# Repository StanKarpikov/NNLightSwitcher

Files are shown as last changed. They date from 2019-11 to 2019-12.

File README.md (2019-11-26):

### NNLightSwitcher - Xilinx Zynq board

The project serves educational purposes, therefore, the maximum number of modules that fit on a small board was used.

Main components on the board:
- Main processing unit: Zynq-7000 SoC (Z-7010) in CLG225 package (FPGA and two ARM Cortex-A9 cores running at 666 MHz)
- Memory: DDR3L 1066 MHz 512 Mb (IS43TR16256AL-125KBL)
- eMMC 8 Gb (MTFC8GAKAJCN-1M WT)
- QSPI Configuration memory (W25Q32JVZPIQ)
- Qi, WPC 1.1 wireless charger 5W (BQ51013BRHLT)
- Battery powering and charging unit (LTC4155EUFD)
- WiFi WLAN(11a/b/g/n/ac) dual band 2.4/5Ghz +BT/BLE(BT5.0) combo SIP module Murata Type1MW with Cypress CYW43455 with chip antenna
- Connectors: USB Type-C (UART), HDMI
- Two MEMS microphones (ICS-40300)

**Hardware** folder includes Altium Designer project for the PCB and schematic.
- Board dimensions: 68 x 42 mm
- Board layers: 6
- Minimum hole: 0.2 mm
- Minimum trace width/gap: 0.1/0.1 mm
- Immersion gold plating (ENIG) is used to ensure surface quality for the BGA chips.

**Enclosure** folder includes STL models for the 3D printed enclosure (made in Blender).

**Software** is in progress. 

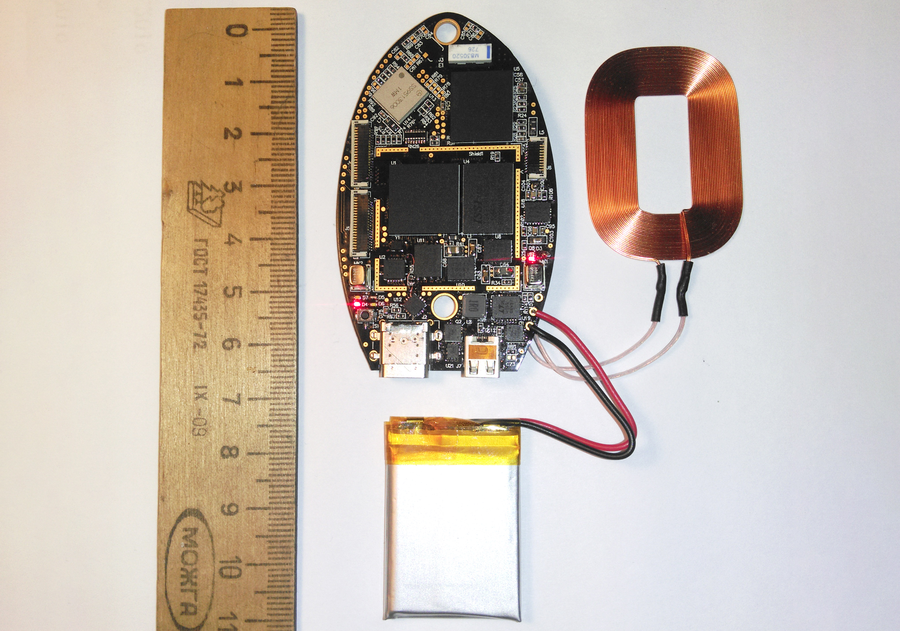
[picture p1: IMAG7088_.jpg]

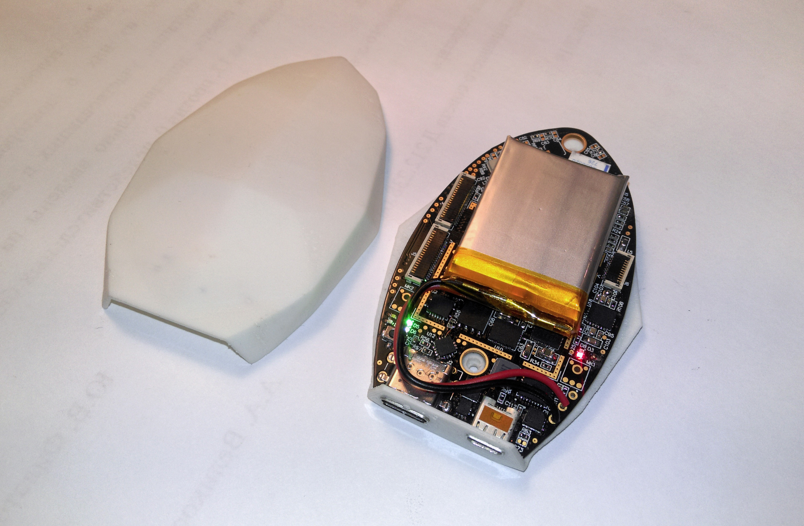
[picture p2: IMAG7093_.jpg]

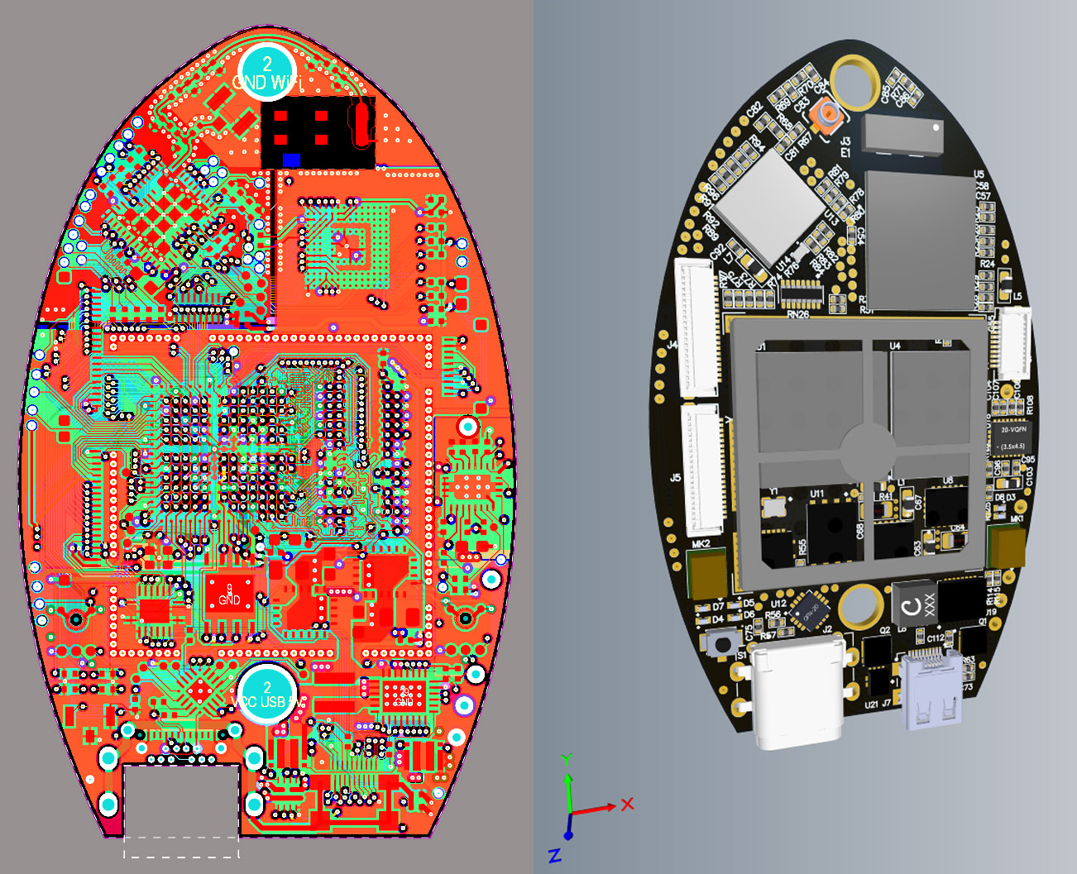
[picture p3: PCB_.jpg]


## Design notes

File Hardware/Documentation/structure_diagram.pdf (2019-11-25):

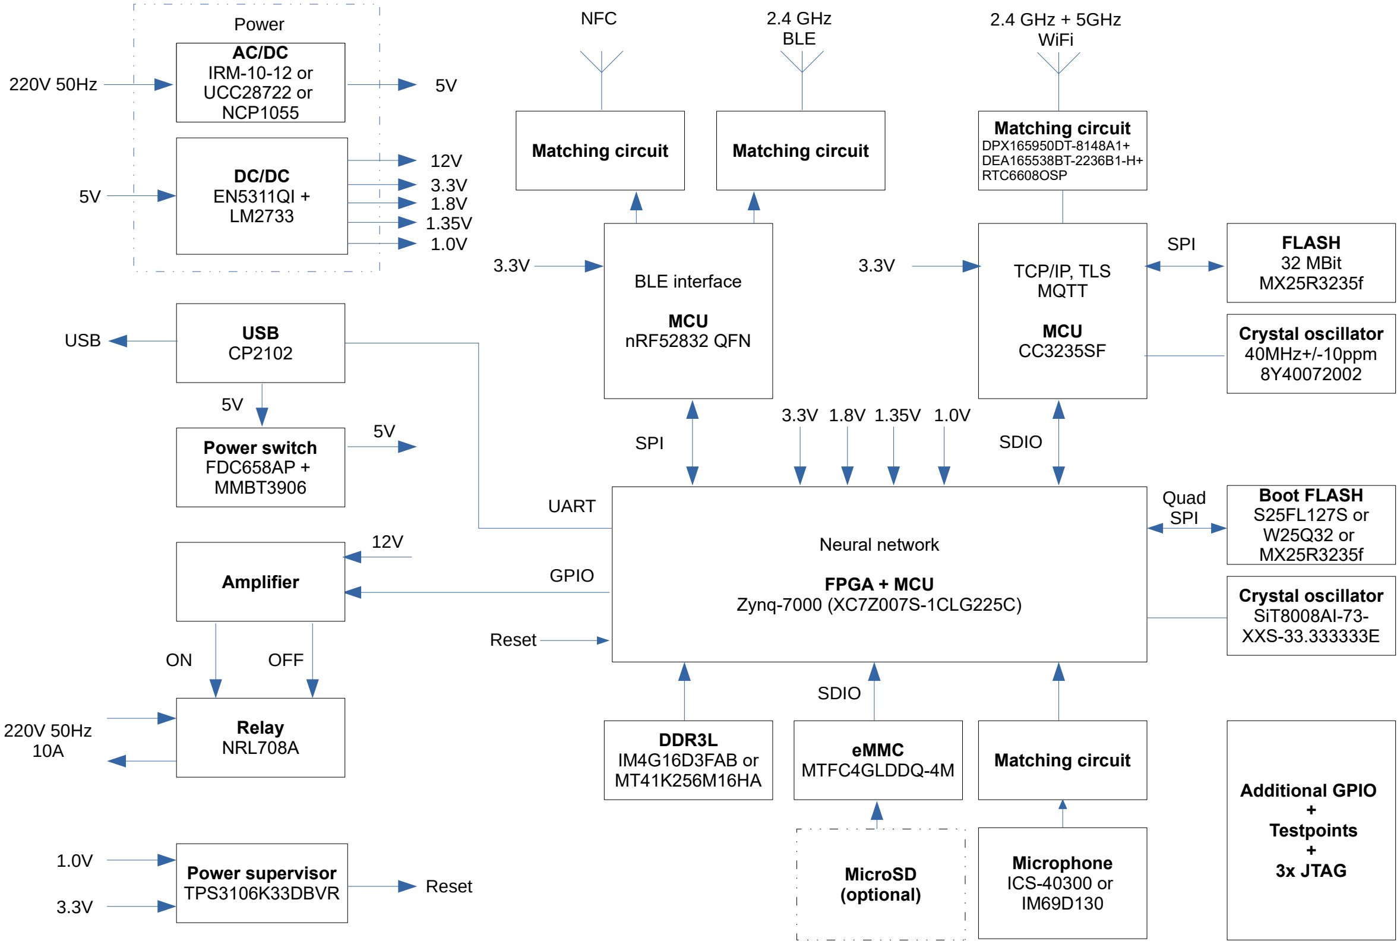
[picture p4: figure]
TCP/IP, TLS MQTT; MCU CC3235SF; FLASH 32 MBit MX25R3235f; Crystal oscillator 40MHz+/-10ppm 8Y40072002; Microphone ICS-40300 or IM69D130; Matching circuit DPX165950DT-8148A1+ DEA165538BT-2236B1-H+ RTC6608OSP; Matching circuit; Relay NRL708A; 2.4 GHz + 5GHz WiFi; AC/DC IRM-10-12 or UCC28722 or NCP1055; SPI; Neural network; FPGA + MCU Zynq-7000 (XC7Z007S-1CLG225C); Boot FLASH S25FL127S or W25Q32 or MX25R3235f; Crystal oscillator SiT8008AI-73- XXS-33.333333E; Quad SPI; BLE interface; MCU nRF52832 QFN; 2.4 GHz BLE; Power; SDIO; Reset; DDR3L IM4G16D3FAB or MT41K256M16HA; eMMC MTFC4GLDDQ-4M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

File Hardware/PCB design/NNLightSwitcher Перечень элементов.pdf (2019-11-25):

Изм. Лист | № докум. | Подп. | Дата
| Разраб. | Карпиков С.Р. | | NNLightSwitcher Перечень элементов | Лит. | Лист | Листов
Пров. | | | | | | | 1

Н.контр.
Утв.

И

нв. №

подл. Подп. и

дата

Взам. инв. №

Инв. №

дубл. Подп. и

дата

Справ. №

Перв. примен.

Поз. обозна-чение | Наименование | Кол. Примечание
U1 | XNLX-XC7Z010-CLG225 Xilinx | 1
U4 | IS43TR16256AL-125KBL ISSI | 1
U5 | MTFC8GAKAJCN-1M WT Micron | 1
U13 | LBEE5HY1MW Murata Electronics | 1
Копировал | Формат A4

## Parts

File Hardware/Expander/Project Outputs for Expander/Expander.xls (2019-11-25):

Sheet: Part List Report
 | Component list |  |  | Bill of Materials for BOM Document [Expander.BomDoc]
 | Source Data From: |  |  | Expander.BomDoc
 | Project: |  |  | Expander.PrjPcb
 | Variant: |  |  | None
 | Report Date: |  | 21-Sep-19 | 11:06
 | Print Date: |  | 2019-09-21 | 11:06:42
# | LibRef | Manufacturer 1 | Manufacturer Part Number 1 | PartType | Description | Footprint | #Column Name Error:' PackageReference | Quantity
1 | FCI_10051922-1010ELF | Amphenol ICC | 10051922-1010ELF | FCI_10051922-1010ELF | 0.50mm FFC/FPC Connectors 10CKT RA SMT ZIF CON BOTTOM CONTACT | *FCI_10051922-1010ELF |  | 1
2 | FCI_10051922-2010ELF | Amphenol FCI | 10051922-2010ELF | FCI_10051922-2010ELF | 0.50mm FFC/FPC Connectors 20CKT RA SMT ZIF CON BOTTOM CONTACT | *FCI_10051922-2010ELF |  | 2
3 | 90131-0765 | Molex | 90131-0765 | 90131-0765 | Connector | HDRV10W90P254_2X5_1260X500X560P |  | 4
4 | 98424-G52-14ALF | Amphenol FCI | 98424-G52-14ALF | 98424-G52-14ALF | Connector | 98424G5214ALF |  | 1
5 | 702461004 | Molex | 702461004 | 702461004 | Connector | SHDR10W99P254_2X5_2032X889X947P |  | 1
6 | BH-20 |  |  | BH-20 | JTAG | BH-20 |  | 1
Approved |  |  |  | Notes |  |  |  | 10

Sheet: Project Information
Project Full Path | E:\REPO_GitHub\NNLightSwitcher\Hardware\Expander\Expander.PrjPcb
Project Filename | Expander.PrjPcb
Variant Name | None
Data-Source Filename | Expander.BomDoc
Data-Source Full Path | E:\REPO_GitHub\NNLightSwitcher\Hardware\Expander\Expander.BomDoc
Title | Bill of Materials for BOM Document [Expander.BomDoc]
Total Quantity | 10
Report Time | 11:06
Report Date | 21-Sep-19
Report Date & Tine | 21-Sep-19 11:06
Output Name | Bill of Materials
Output Type | BOM_PartType
Output Generator Name | BOM
Output Generator Description | Bill of Materials
Total Actual Price | 12.07
Total Target Price | 0

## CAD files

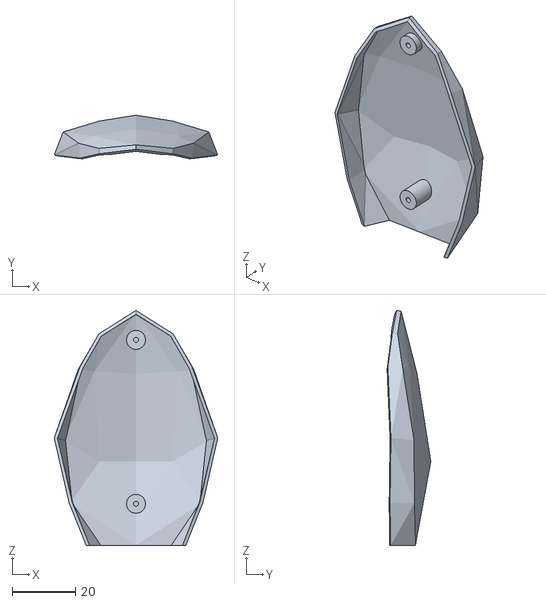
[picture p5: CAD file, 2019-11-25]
Enclosure/Enclosure_cover.STL
51.7 x 13.8 x 74.2

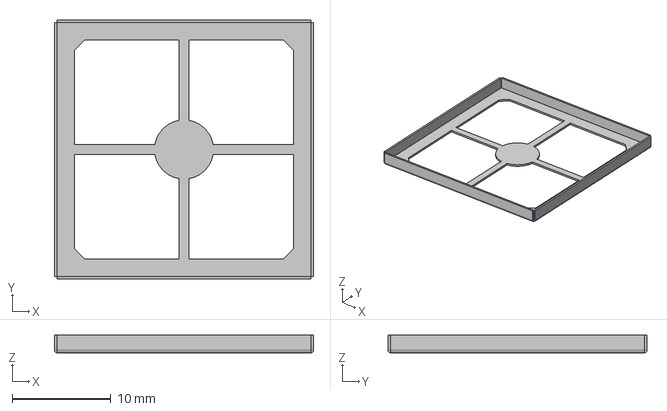
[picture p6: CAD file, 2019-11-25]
Hardware/SMS-252_frame.stp
26.3 x 26.3 x 1.78 mm

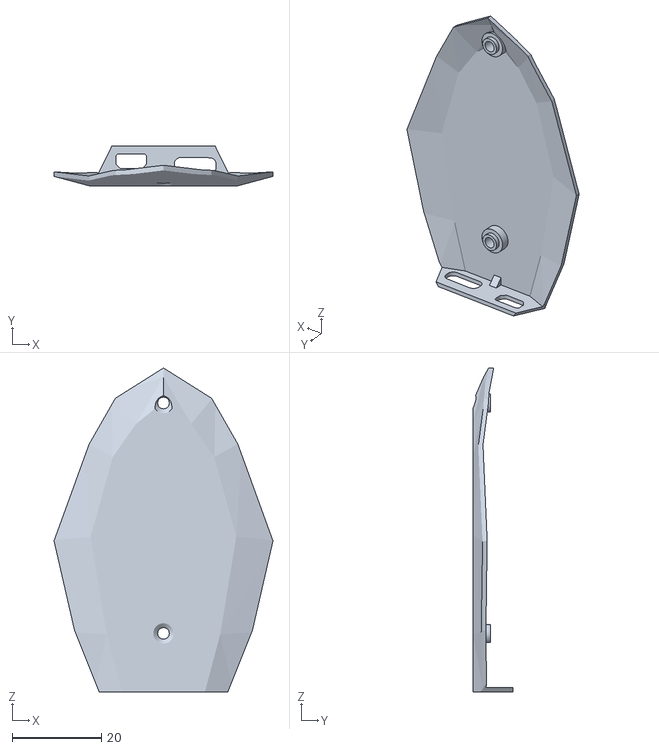
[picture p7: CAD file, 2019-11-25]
Enclosure/Enclosure_base.STL
49.2 x 9.09 x 72.8

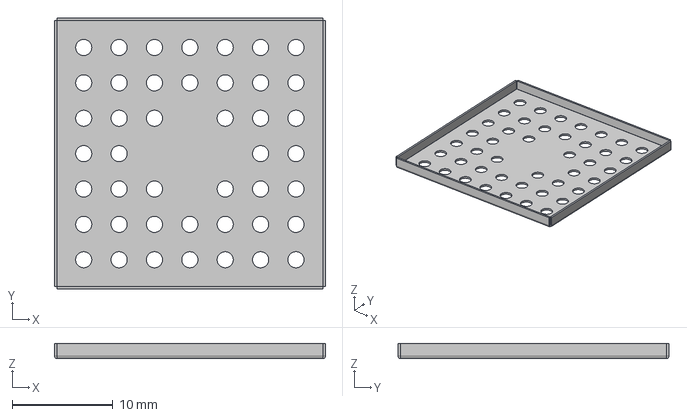
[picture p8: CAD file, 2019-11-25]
Hardware/SMS-252_cover.stp
26.9 x 26.9 x 1.52 mm

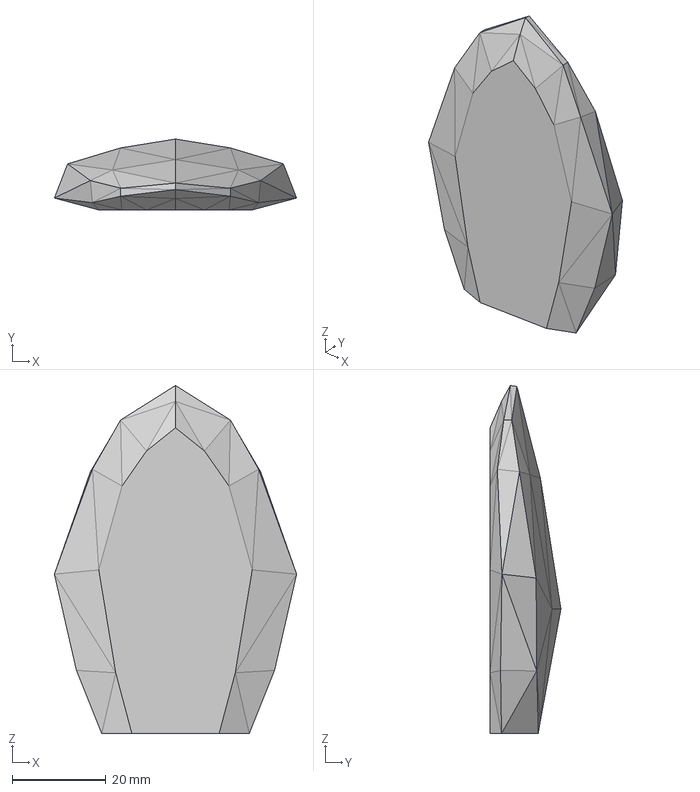
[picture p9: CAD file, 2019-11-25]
Enclosure/Enclosure.stp
51.7 x 15.1 x 74.2 mm

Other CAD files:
Enclosure/Enclosure.blend

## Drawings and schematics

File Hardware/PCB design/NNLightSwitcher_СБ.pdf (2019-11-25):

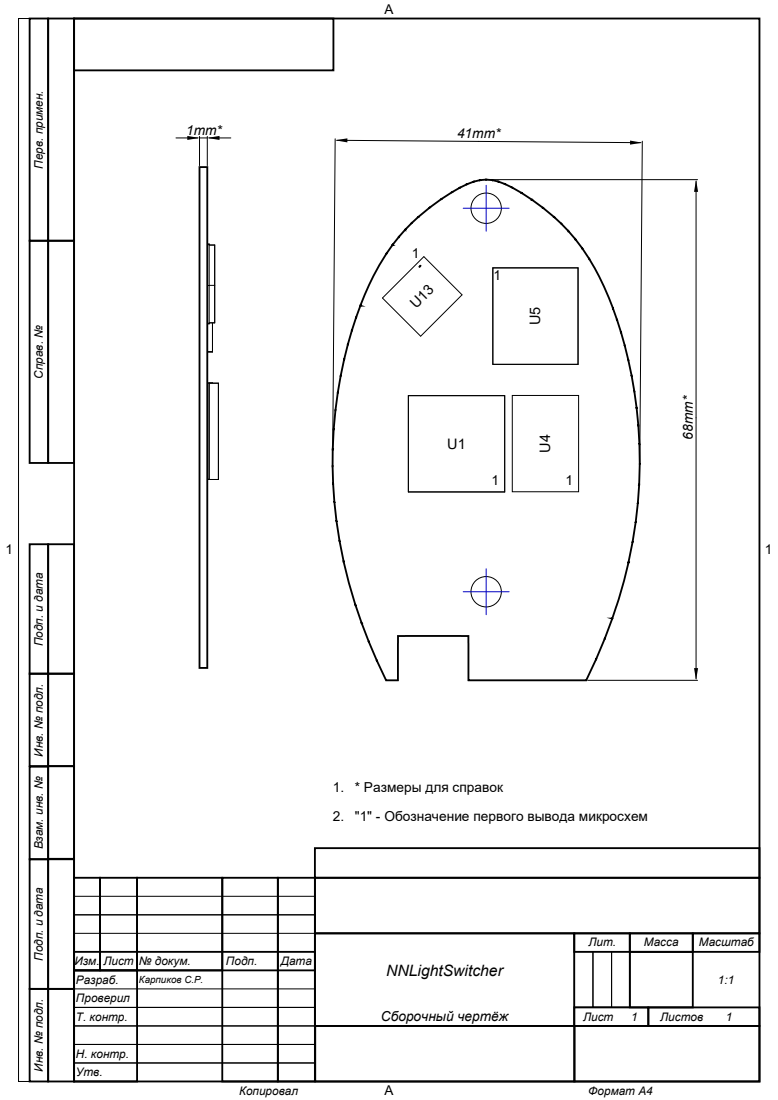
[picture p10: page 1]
Копировал; Формат А4; Сборочный чертёж; Карпиков С.Р.; NNLightSwitcher; Лист; Листов; Лит.; Масса; Масштаб; Утв.; Н. контр.; Подп.; Дата

Перв. примен. Справ. № Подп. и дата Инв. № подл. Взам. инв. № Подп. и дата Инв. № подл.

1. * Размеры для справок

2. "1" - Обозначение первого вывода микросхем

Изм. Лист № докум.
Разраб.
Проверил
Т. контр.

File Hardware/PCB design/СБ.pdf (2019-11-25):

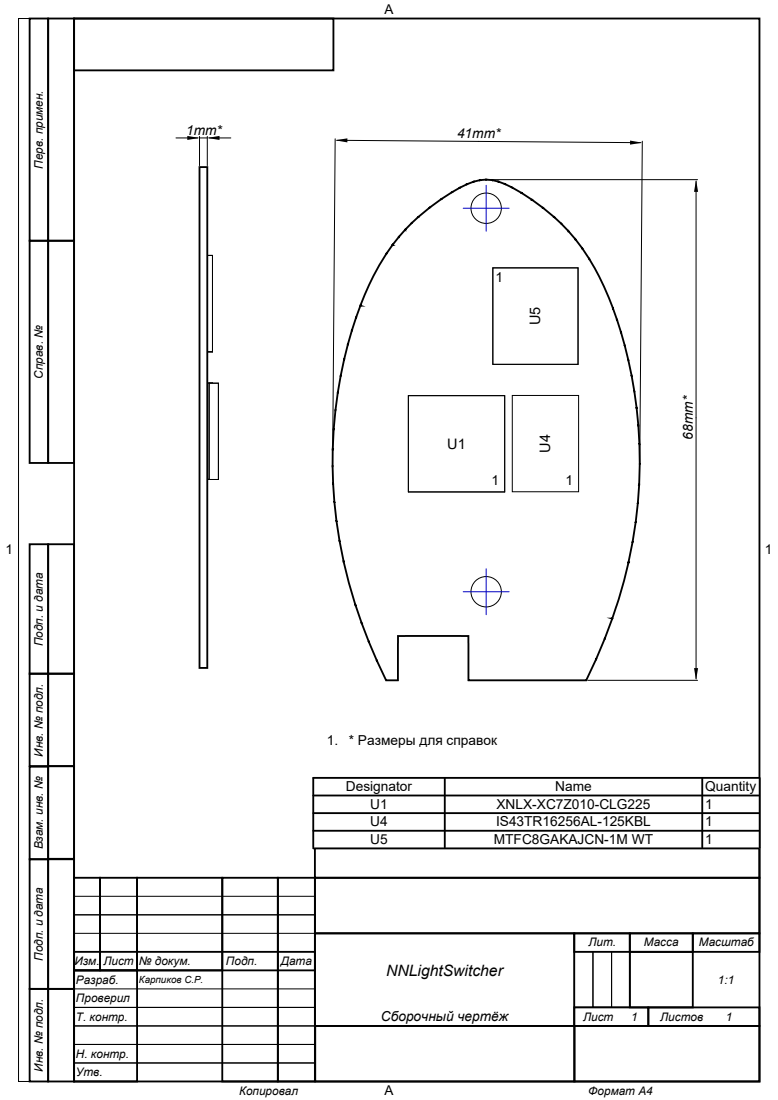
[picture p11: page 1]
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

Перв. примен. Справ. № Подп. и дата Инв. № подл. Взам. инв. № Подп. и дата Инв. № подл.

1. * Размеры для справок

Designator | Name | Quantity
U1 | XNLX-XC7Z010-CLG225 | 1
U4 | IS43TR16256AL-125KBL | 1
U5 | MTFC8GAKAJCN-1M WT | 1

Изм. Лист № докум.
Разраб.
Проверил
Т. контр.

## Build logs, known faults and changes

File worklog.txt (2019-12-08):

*MEMS microphone 
MP34DT05-A
ICS-40300
IM69D130

*esp32
ESP32-D0WD (без памяти) внешняя только до 8Мб
GD25Q32C - Flash
W25Q32
lyontek LY68S3200 - RAM
or ESP-PSRAM32 (esp32 wrover)
23lc1024 (Micron 23A1024)
N01S830HA (ON ) - только 20 МГц и 1Мбит

*STM32WB55 - только BLE

*
Модули:
WiKi статья

STM32 + ATWINC1500,ATWILC3000
Photon (STM32+BCM43362)

TI CC3200

Cypress CYW43012 BCM43362

yum install openssl-devel.x86_64
sudo apt-get install libssl-dev

XMC4800 Infineon

LM832 LM technologies

BX3100 Sierra

RTL8710

LPC54018

EMW3165
-----------------
CC3235SF - но нет внешней RAM памяти.

Zynq-7000 SoC
XC7Z007S-1CLG225C

eMMC - только 3.. , но подходят некоторые 4.1
eMMC - MTFC серия Micron
MTFC4GMVEA-1M - большая
MTFC4GLDDQ-4M - ОК 100-LBGA (14x18)

Xilinx <-> Micron
file:///C:/Users/Stan/Downloads/xilinx_compatibility_guide%20(2).pdf

ZynqBerry

Память DDR3 1.35V FBGA 96 ball

MT41K64M16
IM4G16D3FAB
Micron MT41K256M16HA, MT41K256M16RE, SK Hynix H5TC4G63MFR, H5TC4G63AFR, H5TC4G63BFR, Samsung K4B4G1646Q, K4B4G1646B, K4B4G1646D
-----------------
nRF52 NFC
nRF52832 QFN
NFC Antenna Seed
-----------------
Debug:
Waveshare Platform Cable USB for Zynq
J-link for nRF52 and CC3235SF
-----------------
AC/DC

NCP1055
UCC28722 (PMP9594 - 85-265VACin, 5V/1.5A AC/DC)

LM2733 5V -> 12V or transformer?

900uH Transformer, Discontinuous Mode Flyback, 900uH, TH 17x15x16mm

https://www.power.com/sites/default/files/product-docs/lnk302_304-306.pdf
https://www.onsemi.com/pub/Collateral/AND8099-D.PDF

https://www.fujielectric.com/products/semiconductor/model/power_supply/technical/box/pdf/Fly-Back_transformer_Design_Rev_1_0_E.pdf

----------------
https://github.com/nlbutts/tflite_zynq
github.com/danielholanda/LeFlow
----------------
LG V10 
LG G5
Samsung A7100 
A8000
Samsung Galaxy J5 LTE (SM-J530F)
Samsung Galaxy J7 LTE (SM-J730F)

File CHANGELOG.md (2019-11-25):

### 0.0.1 - Initial release
- Board assembled and tested.

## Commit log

2019-08-07 Webench design files added
    [WBBOMDesign3.csv]
2019-08-07 PCB project initial setup
    [NNLightSwitcher.PcbDoc, NNLightSwitcher.PcbLib, NNLightSwitcher.PrjPcb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]
2019-08-07 Added Zynq, TI, nRF and memory
    [NNLightSwitcher.PcbLib, NNLightSwitcher.SchLib, NNLightSwitcher_main.SchDoc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]
2019-08-08 Add PCB components
    [NNLightSwitcher.PcbDoc, NNLightSwitcher.PcbLib, NNLightSwitcher.PrjPcb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]
2019-08-10 Add schematic components
    [NNLightSwitcher.PcbLib, NNLightSwitcher.SchLib, NNLightSwitcher_main.SchDoc]
2019-08-10 Add CYW43455 WiFi component
    [NNLightSwitcher.PcbLib, NNLightSwitcher.PrjPcb, NNLightSwitcher.SchLib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]
2019-08-13 Add WiFi module power connections
    [NNLightSwitcher.PcbLib, NNLightSwitcher.SchLib, NNLightSwitcher_WiFi.SchDoc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]
2019-08-17 Doing best with CYW43455
    [NNLightSwitcher.SchLib, NNLightSwitcher_DDR3.SchDoc, NNLightSwitcher_QSPI_Flash.SchDoc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]
2019-08-17 Schematic and library improvements
    [NNLightSwitcher.PcbLib, NNLightSwitcher.PrjPcb, NNLightSwitcher.SchLib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]
2019-08-18 Library improvements
    [NNLightSwitcher.PcbLib, NNLightSwitcher.PrjPcb, NNLightSwitcher.SchLib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]
2019-08-19 Change wireless charging IC to Semtech
    [NNLightSwitcher.PcbLib, NNLightSwitcher_1.SCHLIB, NNLightSwitcher_WirelessCharger.SchDoc]
2019-08-21 Add FFC connectors
    [NNLightSwitcher_1.SCHLIB]
2019-08-21 Update library and schematic documents
    [NNLightSwitcher.PrjPcb, NNLightSwitcher.SchLib, NNLightSwitcher_1.SCHLIB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]
2019-08-24 Add enclosure. Add charge sheet. Place components
    [Enclosure.blend, Enclosure.stp, NNLightSwitcher.PrjPcb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]
2019-08-25 Route memories
    [NNLightSwitcher.PrjPcb, NNLightSwitcher.SchLib, NNLightSwitcher_DDR3.SchDoc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]
2019-08-27 Work with Qi Semtech.
    [NNLightSwitcher.PrjPcb, NNLightSwitcher.SchLib, NNLightSwitcher1.PcbLib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]
2019-08-27 Route wireless charger and battery charger
    [NNLightSwitcher.SchLib, NNLightSwitcher_USB.SchDoc, NNLightSwitcher_WirelessCharger.SchDoc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]
2019-08-28 Route WiFi
    [NNLightSwitcher_WiFi.SchDoc, NNLightSwitcher_eMMC_SD.SchDoc]
2019-08-29 HDMI traces and GPIO. Battery charger
2019-08-30 Route GPIO and reset
    [NNLightSwitcher.SchLib, NNLightSwitcher_connectors.SchDoc]
2019-08-31 Route USB, audio, GPIO
    [NNLightSwitcher.SchLib, NNLightSwitcher_DDR3.SchDoc, NNLightSwitcher_USB.SchDoc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]
2019-08-31 Route power nets
    [NNLightSwitcher_QSPI_Flash.SchDoc, NNLightSwitcher_WiFi.SchDoc, NNLightSwitcher_WirelessCharger.SchDoc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]
2019-09-01 Root audio power and polygons
    [NNLightSwitcher.PrjPcb, NNLightSwitcher.SchLib, NNLightSwitcher_USB.SchDoc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]
2019-09-01 Resolve violations
    [NNLightSwitcher.SchLib]
2019-09-01 Route polygons
    [NNLightSwitcher.SchLib, NNLightSwitcher_USB.SchDoc, NNLightSwitcher_WiFi.SchDoc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]
2019-09-03 DDR3 traces rework
    [NNLightSwitcher.PrjPcb, NNLightSwitcher_DDR3.SchDoc, NNLightSwitcher_Zynq.SchDoc]
2019-09-04 Match DDR3 trace length
2019-09-05 Match HDMI, SDIO length
    [NNLightSwitcher_WiFi.SchDoc, NNLightSwitcher_eMMC_SD.SchDoc]
2019-09-06 Rework traces and components
    [NNLightSwitcher.PrjPcb, NNLightSwitcher_WiFi.SchDoc, NNLightSwitcher_WirelessCharger.SchDoc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]
2019-09-07 Rework schematic and PCB
    [NNLightSwitcher.PrjPcb, NNLightSwitcher.SchLib, NNLightSwitcher_DDR3.SchDoc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]
2019-09-07 BOM create
    [NNLightSwitcher.SchLib, NNLightSwitcher_WiFi.SchDoc]
2019-09-12 Minor changes
    [NNLightSwitcher_charge.SchDoc, NNLightSwitcher_connectors.SchDoc, NNLightSwitcher_power.SchDoc]
2019-09-14 Add expander schematics and PCB
    [Expander.PcbDoc, Expander.PcbLib, Expander.PrjPcb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]
2019-09-15 Try to change millimmeters to mill in dimensions
    [Expander.PcbDoc, Expander.PrjPcb, Expander.SchDoc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]
2019-09-16 Fix violations
    [Expander.PrjPcb, NNLightSwitcher.PrjPcb, NNLightSwitcher.SchLib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]
2019-09-19 Rematch length DDR3
    [NNLightSwitcher.PrjPcb]
2019-09-20 Preparation for manufacturing
    [Expander.PcbDoc, NNLightSwitcher.PrjPcb]
2019-09-22 Add outjob files and work with BOM.
    [Expander.PcbDoc, Expander.PrjPcb, Expander.xls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]
2019-09-23 Add panel board
    [Board_array.PcbDoc]
2019-09-23 Change panel board outline
    [Board_array.PcbDoc, Copy of Board_array.PcbDoc, Expander.PcbDoc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]
2019-09-24 Resolve manufacturing polygon violations
    [NNLightSwitcher.PrjPcb]
2019-09-25 Resolve manufacturing polygon violations (continue)
    [NNLightSwitcher.PrjPcb]
2019-09-28 Add PCB variants and assemble drawing
    [NNLightSwitcher.PrjPcb, NNLightSwitcher_Zynq.SchDoc, NNLightSwitcher_eMMC_SD.SchDoc]
2019-11-25 Fig bugs with USB RX and TX, USB V sense, eMMC Vddim
    [Enclosure_base.STL, Enclosure_cover.STL, NNLightSwitcher.PrjPcb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]
2019-12-14 Checkout current branch
